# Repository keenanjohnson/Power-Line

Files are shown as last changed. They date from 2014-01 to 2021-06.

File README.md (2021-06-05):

###Current design###
4 "devices", communication is from top to bottom and vice versa:

* Arduino + Ethernet Shield -> (Ethernet cable) -> Router
* Router -> (Ethernet cable) -> PLN 1
* PLN 1 -> power line -> PLN 2
* PLN 2 -> (Ethernet cable) -> Arduino + Ethernet Sheild

####Information####
Ensure that the node devices all have different MAC addresses to get different IP addresses from the host router. The router should be set up to deliver a certain IP address to the MAC address of the base station. In our project's current state, it is meant to be delivered 192.168.2.50 but will setup its own IP address if that one is unobtainable. The nodes will just listen for the IP address so this is mainly important for access the website, which you will require you to know the IP address.

###Powerline###
Powerline

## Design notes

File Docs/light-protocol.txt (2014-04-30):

LIGHT PROTOCOL
DRAFT v2, 29 April 2014

The packets sent in the light protocol start with an identifier byte of 0x01, followed by protocol-specific information.

The protocol-specific information consists of a one-byte node identifier, a one-byte command, and a one-byte data field.

Nodes should only interpret a command whose node identifier byte matches their stored identifier. The implemented commands are as follows:

NODE_OFF = 0
Turn the light attached to a node off.

NODE_ON = 1
Turn the light attached to a node on.

NODE_SAVE_ID = 2
Set the stored identifier of a node to the data byte.

NODE_KEEP_ALIVE = 3
Ping message sent to ensure transport liveness.

NODE_STATUS = 4
Send the status of a node to the server in the data byte, using 0 for off and 1 for on.

In packets for which the command byte does not specify a command which uses the data byte, the value in the data byte is unspecified and should be ignored.

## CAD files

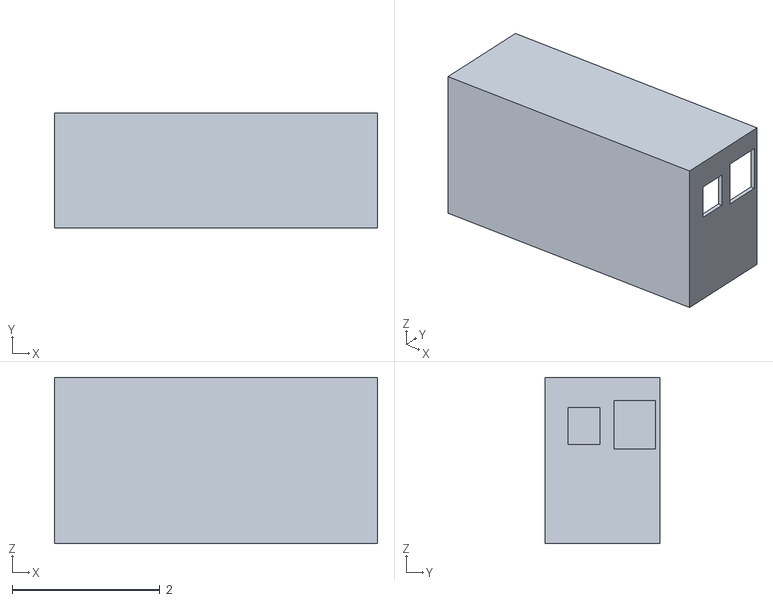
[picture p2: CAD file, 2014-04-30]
Hardware/PhysicalHousing/SD_BaseStation_Box.stl
4.37 x 1.56 x 2.25

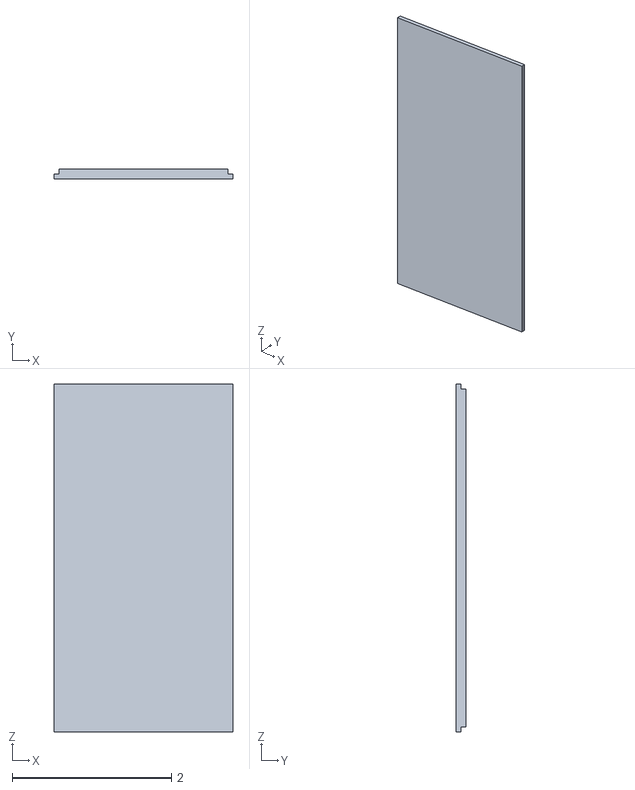
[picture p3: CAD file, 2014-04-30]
Hardware/PhysicalHousing/SD_BaseStation_Lid.stl
2.25 x 0.125 x 4.38

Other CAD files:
Hardware/PhysicalHousing/SD_BaseStation_Box.ipt
Hardware/PhysicalHousing/SD_BaseStation_Enclosure.iam
Hardware/PhysicalHousing/SD_BaseStation_Lid.ipt

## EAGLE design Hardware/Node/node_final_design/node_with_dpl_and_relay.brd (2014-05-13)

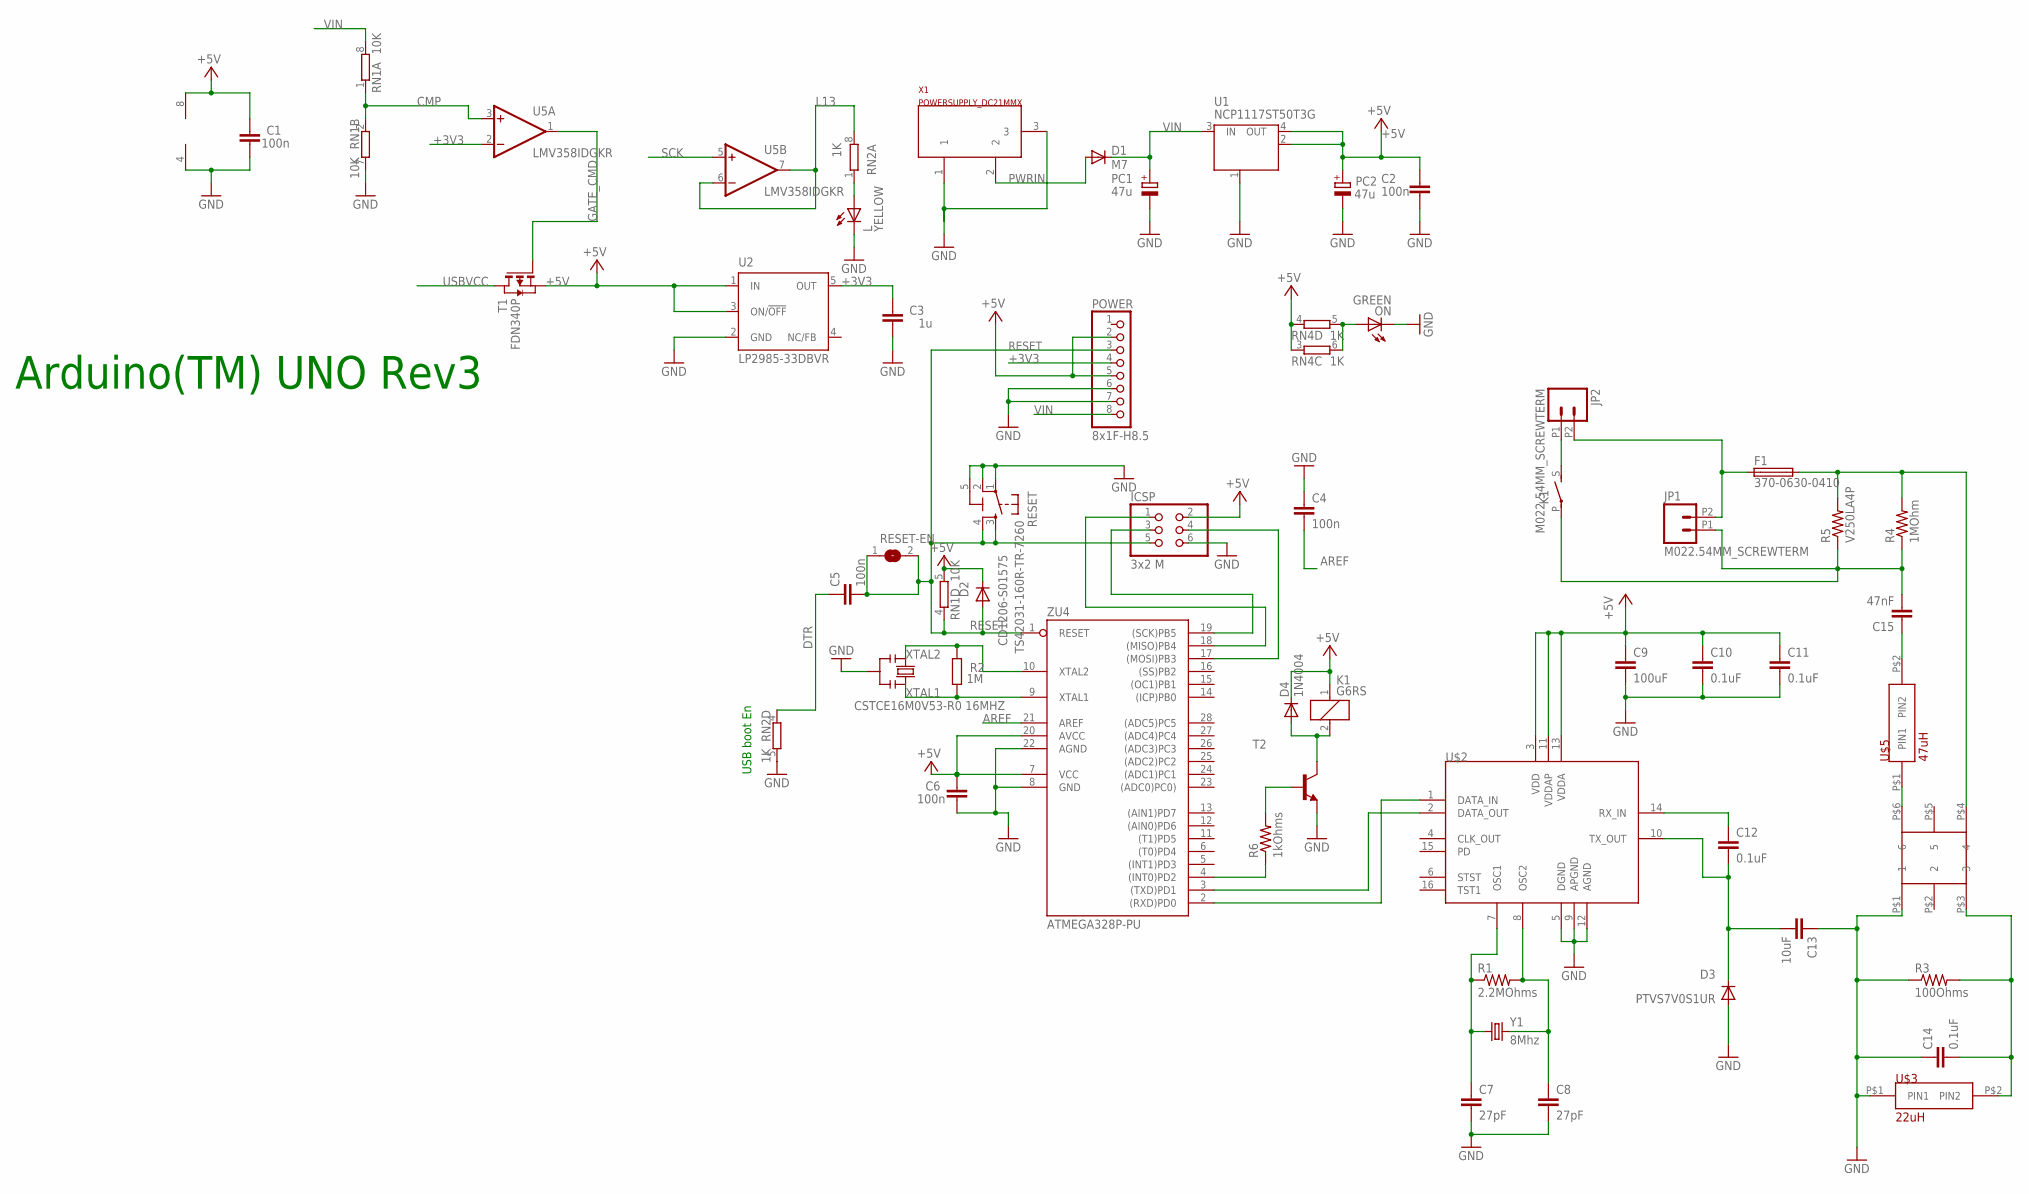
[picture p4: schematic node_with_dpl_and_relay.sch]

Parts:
C1, C2, C4, C5, C6: 100n; C0603-ROUND
C3: 1u; C0603-ROUND
C7, C8: 27pF; 1206
C9: 100uF; 1206
C10, C11, C14: 0.1uF; 1206
C12: 0.1uF; AXIAL-5MM
C13: 10uF; CAP-PTH-SMALL
C15: 47nF; C15B5
D1: M7; SMB
D2: CD1206-S01575; MINIMELF
D3: PTVS7V0S1UR; SOD-123_MINI-SMA
D4: 1N4004; DO41-10
F1: 370-0630-0410; TR5
ICSP: 3x2 M; 2X03
JP1, JP2: M022.54MM_SCREWTERM; 1X02_2.54_SCREWTERM
K1: G6RS
L: YELLOW; CHIP-LED0805
ON: GREEN; CHIP-LED0805
PC1, PC2: 47u; PANASONIC_D
POWER: 8x1F-H8.5; 1X08
R1: 2.2MOhms; 1206
R2: 1M; R0603-ROUND
R3: 100Ohms; AXIAL-0.5
R4: 1MOhm; AXIAL-0.3-KIT
R5: V250LA4P; AXIAL-0.4
R6: 1kOhms; 0204V
RESET: TS42031-160R-TR-7260; TS42
RESET-EN: SJ
RN1: 10K; CAY16
RN2, RN4: 1K; CAY16
T1: FDN340P; SOT-23
T2: 2N5401-NPN-TO92-CBE; TO92-CBE
U1: NCP1117ST50T3G; SOT223
U2: LP2985-33DBVR; SOT23-DBV
U5: LMV358IDGKR; MSOP08
U$2: TDA5052AT; SO16L
U$3: 22uH; RFB0807-220L
U$4: 78250MC
U$5: 47uH; RFB0807-220L
X1: POWERSUPPLY_DC21MMX; POWERSUPPLY_DC-21MM
Y1: 8Mhz; HC49US
Y2: CSTCE16M0V53-R0 16MHZ; RESONATOR
ZU4: ATMEGA328P-PU; DIL28-3

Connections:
+3V3: C3.2, POWER.4, U2.5 (OUT), U5.2 (-IN)
+5V: C1.2, C2.2, C6.2, C9.1, C10.1, C11.1, D2.C, D4.C, ICSP.2, K1.1, PC2.+, POWER.2, POWER.5, RN1.5 (2), RN4.3 (1), RN4.4 (1), T1.2 (S), U1.2 (OUT), U1.4 (OUT), U2.1 (IN), U2.3 (ON/!OFF), U5.8 (V+), U$2.3 (VDD), U$2.11 (VDDAP), U$2.13 (VDDA), ZU4.7 (VCC), ZU4.20 (AVCC)
AREF: C4.2, ZU4.21 (AREF)
CMP: RN1.1, RN1.2 (1), U5.3 (+IN)
DTR: C5.1, RN2.4 (1)
GATE_CMD: T1.3 (G), U5.1 (OUT)
GND: C1.1, C2.1, C3.1, C4.1, C6.1, C7.2, C8.2, C9.2, C10.2, C11.2, C13.1, C14.1, D3.A, ICSP.6, L.C, ON.C, PC1.-, PC2.-, POWER.6, POWER.7, R3.P$1 (1), RESET.1, RESET.2, RESET.5 (5-GND), RN1.7 (2), RN2.5 (2), T2.E, U1.1 (GND/ADJ), U2.2 (GND), U5.4 (V-), U$2.5 (DGND), U$2.9 (APGND), U$2.12 (AGND), U$3.P$1 (PIN1), U$4.P$1 (1), X1.1, X1.3, Y2.2, ZU4.8 (GND), ZU4.22 (AGND)
L13: RN2.8 (2), U5.6 (-IN), U5.7 (OUT)
MISO: ICSP.1, ZU4.18 ((MISO)PB4)
MOSI: ICSP.4, ZU4.17 ((MOSI)PB3)
unnamed: L.A, RN2.1
unnamed: C8.1, R1.2, U$2.8 (OSC2), Y1.2
unnamed: ON.A, RN4.5 (2), RN4.6 (2)
unnamed: C7.1, R1.1, U$2.7 (OSC1), Y1.1
unnamed: C12.P$1 (1), U$2.14 (RX_IN)
unnamed: C12.P$2 (2), C13.2, D3.C, U$2.10 (TX_OUT)
unnamed: C14.2, R3.P$2 (2), U$3.P$2 (PIN2), U$4.P$3 (3)
unnamed: U$4.P$6 (6), U$5.P$1 (PIN1)
unnamed: C15.1, U$5.P$2 (PIN2)
unnamed: F1.2, R4.P$2 (2), R5.P$2 (2), U$4.P$4 (4)
unnamed: JP2.P1 (1), K1.S
unnamed: F1.1, JP1.P2 (2), JP2.P2 (2)
unnamed: U$2.2 (DATA_OUT), ZU4.3 ((TXD)PD1)
unnamed: U$2.1 (DATA_IN), ZU4.2 ((RXD)PD0)
unnamed: R6.1, ZU4.4 ((INT0)PD2)
unnamed: R6.2, T2.B
unnamed: D4.A, K1.2, T2.C
unnamed: C15.2, JP1.P1 (1), K1.P, R4.P$1 (1), R5.P$1 (1)
PWRIN: D1.A, X1.2
RESET: C5.2, D2.A, ICSP.5, POWER.3, RESET.3, RESET.4, RESET-EN.1, RESET-EN.2, RN1.4 (1), ZU4.1 (RESET)
SCK: ICSP.3, U5.5 (+IN), ZU4.19 ((SCK)PB5)
USBVCC: T1.1 (D)
VIN: D1.C, PC1.+, POWER.8, RN1.8 (2), U1.3 (IN)
XTAL1: R2.1, Y2.3, ZU4.9 (XTAL1)
XTAL2: R2.2, Y2.1, ZU4.10 (XTAL2)

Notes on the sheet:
Arduino(TM) UNO Rev3
USB boot En

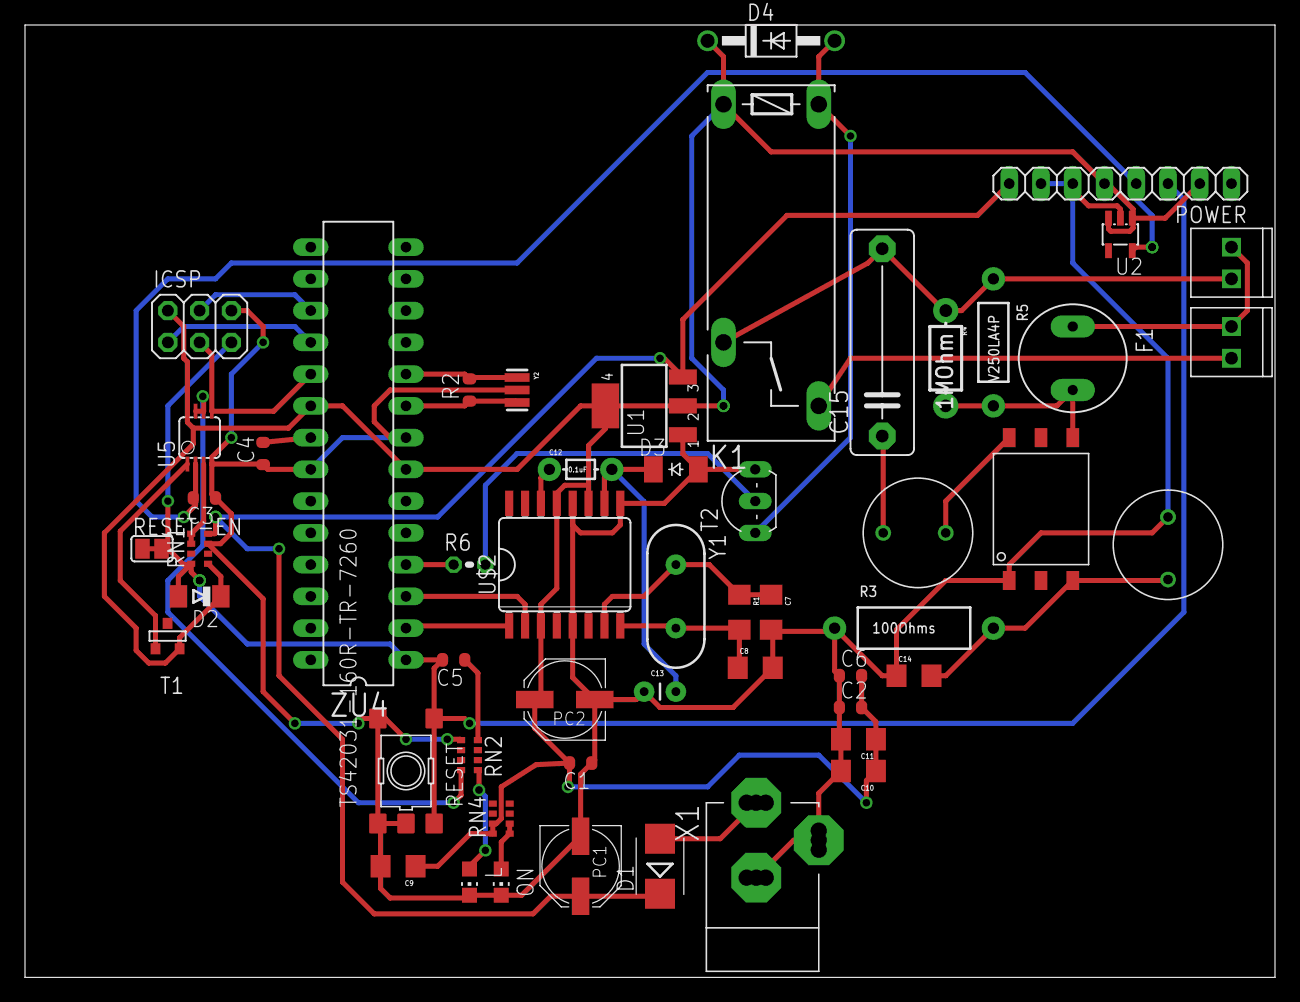
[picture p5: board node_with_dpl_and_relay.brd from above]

Board: 2 copper layers, 100.0 x 76.2 mm, 53 parts (0 on the bottom side), 34 nets.

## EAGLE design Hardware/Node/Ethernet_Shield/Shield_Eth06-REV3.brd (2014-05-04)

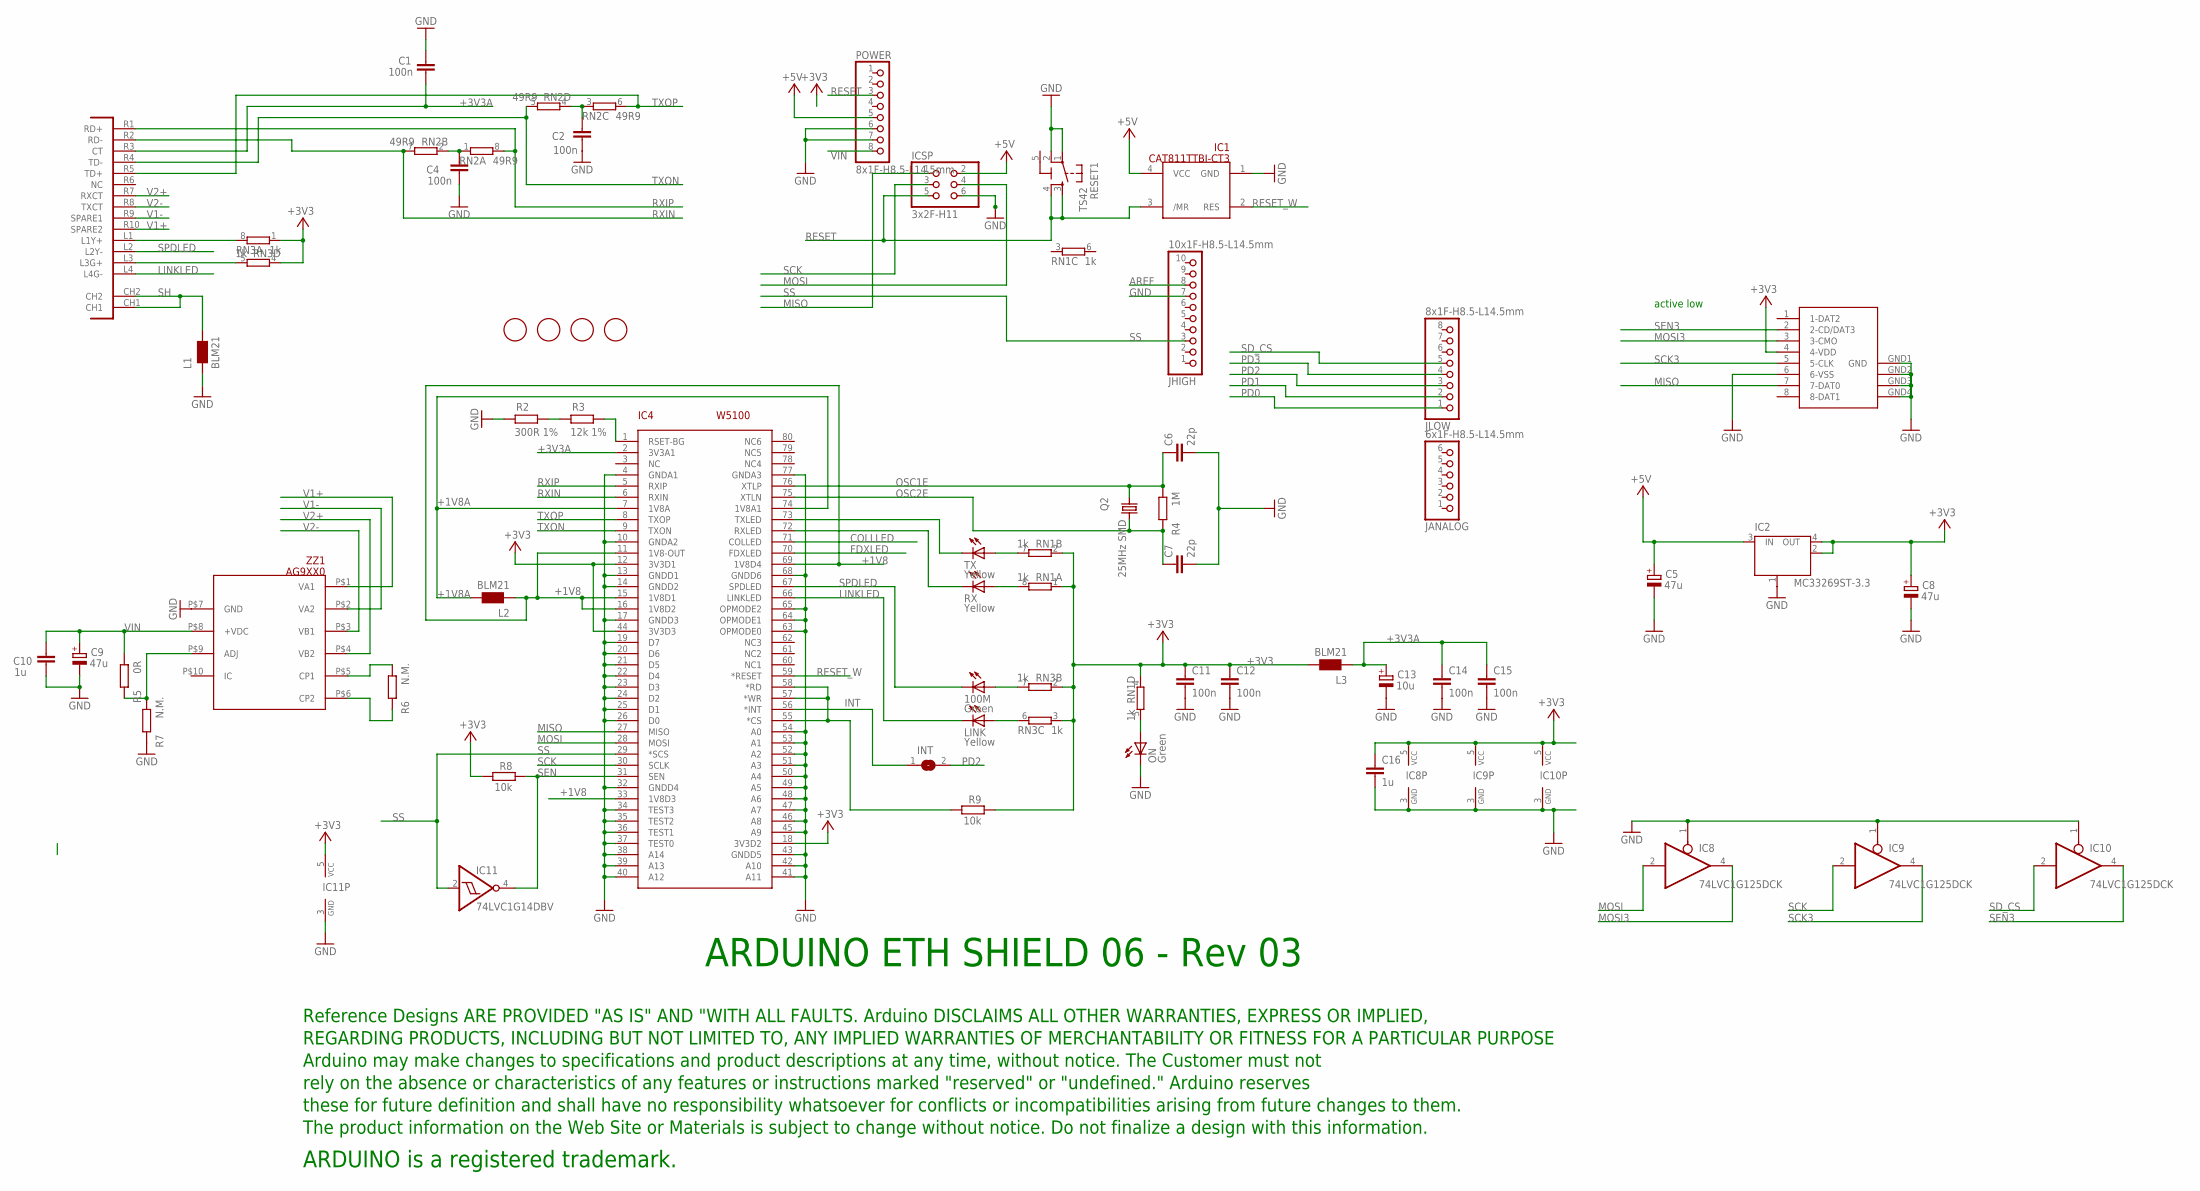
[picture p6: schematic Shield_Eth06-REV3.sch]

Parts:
100M: Green; CHIPLED_0805
C1, C2, C4, C11, C12, C14, C15: 100n; C0603-ROUND
C5, C8, C9: 47u; PANASONIC_D
C6, C7: 22p; C0603-ROUND
C10, C16: 1u; C0603-ROUND
C13: 10u; SMC_B
FID1, FID2, FID3, FID4: FIDUCIALMOUNT; FIDUCIA-MOUNT
IC1: CAT811TTBI-CT3; SOT143
IC2: MC33269ST-3.3; SOT223
IC4: W5100; SQFP-S-10X10-80
IC8, IC9, IC10: 74LVC1G125DCK; SC70-5
IC11: 74LVC1G14DBV; SOT23-5
ICSP: 3x2F-H11; 2X03
INT: SJ
JANALOG: 6x1F-H8.5-L14.5mm; 1X06
JHIGH: 10x1F-H8.5-L14.5mm; 1X10
JLOW: 8x1F-H8.5-L14.5mm; 1X08
L1, L2, L3: BLM21; 0805
LINK: Yellow; CHIPLED_0805
ON: Green; CHIPLED_0805
POWER: 8x1F-H8.5-L14.5mm; 1X08
Q2: 25MHz SMD; HC49UP
R2: 300R 1%; R0603-ROUND
R3: 12k 1%; R0603-ROUND
R4: 1M; R0603-ROUND
R5: 0R; R0603-ROUND
R6, R7: N.M.; R0603-ROUND
R8, R9: 10k; R0603-ROUND
RESET1: TS42
RN1, RN3: 1k; CAY16
RN2: 49R9; CAY16
RX: Yellow; CHIPLED_0805
TX: Yellow; CHIPLED_0805
U$1: POE-RJ45
U$2: DISCLAIMER
X1: SDCARD-15TW-8821
ZZ1: AG9XX0; AG9000

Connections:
5-GND: RESET1.5 (5-GND)
+1V8: IC4.11 (1V8-OUT), IC4.15 (1V8D1), IC4.16 (1V8D2), IC4.33 (1V8D3), IC4.69 (1V8D4), L2.1
+1V8A: IC4.7 (1V8A), IC4.74 (1V8A1), L2.2
+3V3: C8.+, C11.1, C12.1, C16.1, IC2.2 (OUT), IC2.4 (OUT), IC4.12 (3V3D1), IC4.18 (3V3D2), IC4.44 (3V3D3), IC8.5 (VCC), IC9.5 (VCC), IC10.5 (VCC), IC11.5 (VCC), L3.2, R8.1, R9.2, RN1.1, RN1.2 (1), RN1.4 (1), RN3.1, RN3.2 (1), RN3.3 (1), RN3.4 (1), X1.4 (4-VDD)
+3V3A: C1.1, C13.+, C14.1, C15.1, IC4.2 (3V3A1), L3.1, U$1.R3 (CT)
+5V: C5.+, IC1.4 (VCC), IC2.3 (IN), ICSP.2, POWER.5
AREF: JHIGH.8
COLLLED: IC4.71 (COLLED)
FDXLED: IC4.70 (FDXLED)
GND: C1.2, C2.1, C4.1, C5.-, C6.2, C7.2, C8.-, C9.-, C10.1, C11.2, C12.2, C13.-, C14.2, C15.2, C16.2, IC1.1 (GND), IC2.1 (GND/ADJ), IC4.4 (GNDA1), IC4.10 (GNDA2), IC4.13 (GNDD1), IC4.14 (GNDD2), IC4.17 (GNDD3), IC4.19 (D7), IC4.20 (D6), IC4.21 (D5), IC4.22 (D4), IC4.23 (D3), IC4.24 (D2), IC4.25 (D1), IC4.26 (D0), IC4.32 (GNDD4), IC4.34 (TEST3), IC4.35 (TEST2), IC4.36 (TEST1), IC4.37 (TEST0), IC4.38 (A14), IC4.39 (A13), IC4.40 (A12), IC4.41 (A11), IC4.42 (A10), IC4.43 (GNDD5), IC4.45 (A9), IC4.46 (A8), IC4.47 (A7), IC4.48 (A6), IC4.49 (A5), IC4.50 (A4), IC4.51 (A3), IC4.52 (A2), IC4.53 (A1), IC4.54 (A0), IC4.63 (OPMODE0), IC4.64 (OPMODE1), IC4.65 (OPMODE2), IC4.68 (GNDD6), IC4.77 (GNDA3), IC8.1 (OE), IC8.3 (GND), IC9.1 (OE), IC9.3 (GND), IC10.1 (OE), IC10.3 (GND), IC11.3 (GND), ICSP.6, JHIGH.7, L1.1, ON.C, POWER.6, POWER.7, R2.2, R7.2, RESET1.1, RESET1.2, X1.6 (6-VSS), X1.GND1 (GND), X1.GND2 (GND1), X1.GND3 (GND2), X1.GND4 (GND3), ZZ1.P$7 (GND)
INT: IC4.56 (*INT), INT.1
LINKLED: IC4.66 (LINKLED), LINK.C, U$1.L4 (L4G-)
MISO: IC4.27 (MISO), ICSP.1, X1.7 (7-DAT0)
MOSI: IC4.28 (MOSI), IC8.2 (I), ICSP.4
MOSI3: IC8.4 (O), X1.3 (3-CMO)
unnamed: RN3.5 (2), U$1.L3 (L3G+)
unnamed: RN3.8 (2), U$1.L1 (L1Y+)
unnamed: IC4.73 (TXLED), TX.C
unnamed: IC4.72 (RXLED), RX.C
unnamed: ON.A, RN1.5 (2)
unnamed: RN1.7 (2), TX.A
unnamed: C2.2, RN2.3 (1), RN2.4 (1)
unnamed: RN1.8 (2), RX.A
unnamed: 100M.A, RN3.7 (2)
unnamed: LINK.A, RN3.6 (2)
unnamed: C4.2, RN2.1, RN2.2 (1)
unnamed: R2.1, R3.2
unnamed: IC4.1 (RSET-BG), R3.1
unnamed: R6.1, ZZ1.P$5 (CP1)
unnamed: R6.2, ZZ1.P$6 (CP2)
unnamed: R5.2, R7.1, ZZ1.P$9 (ADJ)
unnamed: IC4.55 (*CS), IC4.57 (*WR), IC4.58 (*RD), R9.1
OSC1E: C6.1, IC4.76 (XTLP), Q2.1, R4.1
OSC2E: C7.1, IC4.75 (XTLN), Q2.2, R4.2
PD0: JLOW.1
PD1: JLOW.2
PD2: INT.2, JLOW.3
PD3: JLOW.4
RESET: IC1.3 (/MR), ICSP.5, POWER.3, RESET1.3, RESET1.4
RESET_W: IC1.2 (RES), IC4.59 (*RESET)
RXIN: IC4.6 (RXIN), RN2.7 (2), U$1.R2 (RD-)
RXIP: IC4.5 (RXIP), RN2.8 (2), U$1.R1 (RD+)
SCK: IC4.30 (SCLK), IC9.2 (I), ICSP.3
SCK3: IC9.4 (O), X1.5 (5-CLK)
SD_CS: IC10.2 (I), JLOW.5
SEN: IC4.31 (SEN), IC11.4 (O), R8.2
SEN3: IC10.4 (O), X1.2 (2-CD/DAT3)
SH: L1.2, U$1.CH1, U$1.CH2
SPDLED: 100M.C, IC4.67 (SPDLED), U$1.L2 (L2Y-)
SS: IC4.29 (*SCS), IC11.2 (I), JHIGH.3
TXON: IC4.9 (TXON), RN2.5 (2), U$1.R4 (TD-)
TXOP: IC4.8 (TXOP), RN2.6 (2), U$1.R5 (TD+)
V1+: U$1.R10 (SPARE2), ZZ1.P$1 (VA1)
V1-: U$1.R9 (SPARE1), ZZ1.P$2 (VA2)
V2+: U$1.R7 (RXCT), ZZ1.P$4 (VB2)
V2-: U$1.R8 (TXCT), ZZ1.P$3 (VB1)
VIN: C9.+, C10.2, POWER.8, R5.1, ZZ1.P$8 (+VDC)

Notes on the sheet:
ARDUINO ETH SHIELD 06 - Rev 03
active low

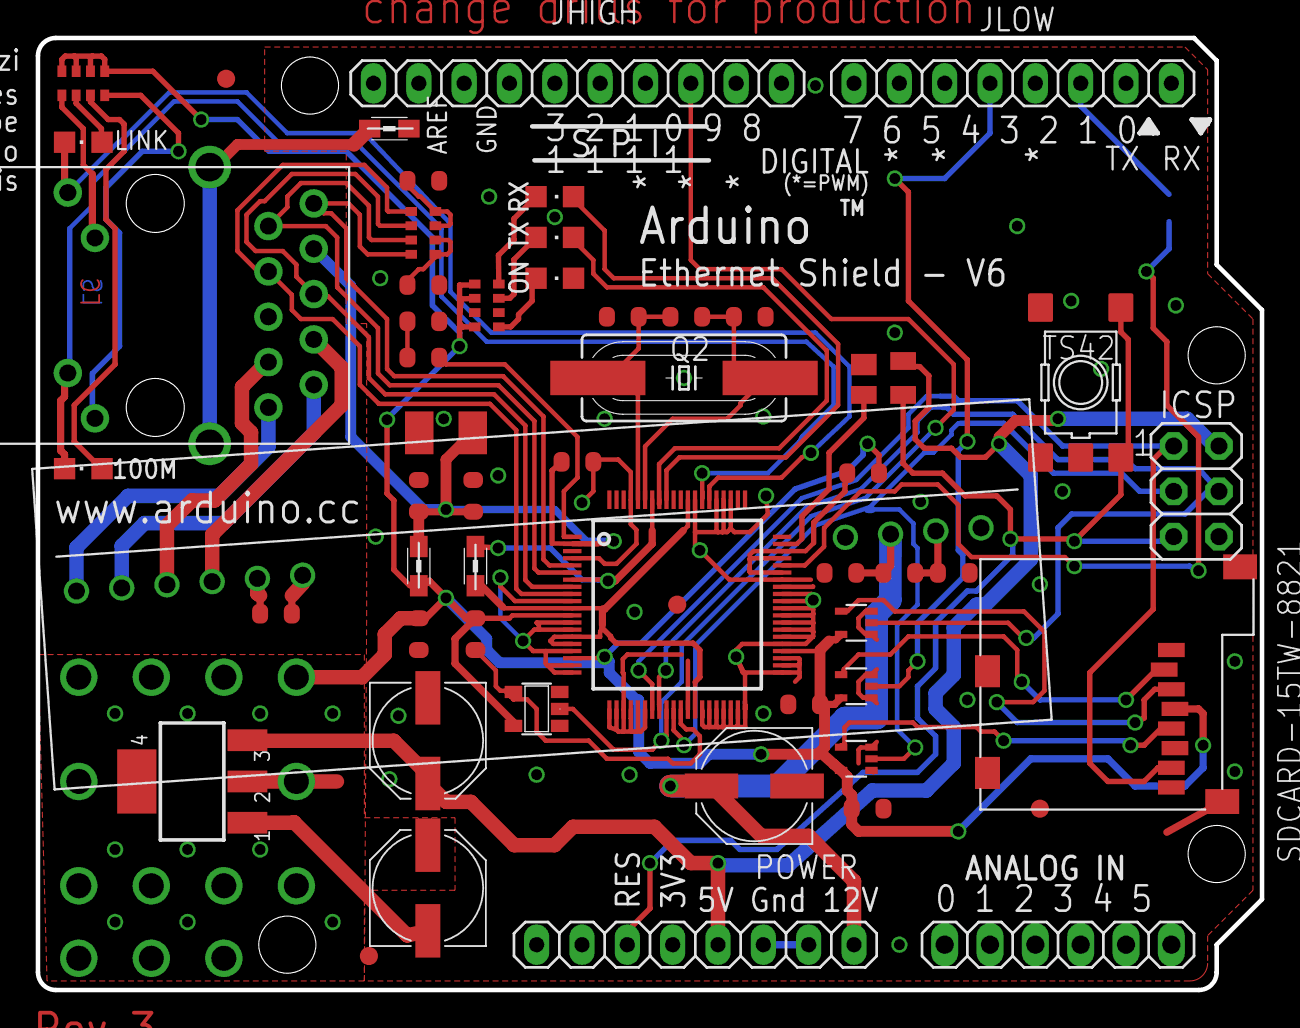
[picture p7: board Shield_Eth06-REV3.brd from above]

Board: 2 copper layers, 68.6 x 53.3 mm, 57 parts (1 on the bottom side), 50 nets.

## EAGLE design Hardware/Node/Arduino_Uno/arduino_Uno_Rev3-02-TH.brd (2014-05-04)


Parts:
AD: 6x1F-H8.5; 1X06
C1, C2, C4, C5, C6, C7: 100n; C0603-ROUND
C3, C8: 1u; C0603-ROUND
C9, C11: 22p; C0603-ROUND
D1: M7; SMB
D2, D3: CD1206-S01575; MINIMELF
F1: MF-MSMF050-2 500mA; L1812
FD1, FD2, FD3: FIDUCIALMOUNT; FIDUCIA-MOUNT
GROUND: SJ
ICSP, ICSP1: 3x2 M; 2X03
IOH: 10x1F-H8.5; 1X10
IOL: 8x1F-H8.5; 1X08
JP2: 2x2 M - NM; 2X02
L: YELLOW; CHIP-LED0805
L1: BLM21; 0805
ON: GREEN; CHIP-LED0805
PC1, PC2: 47u; PANASONIC_D
POWER: 8x1F-H8.5; 1X08
R1, R2: 1M; R0603-ROUND
RESET: TS42031-160R-TR-7260; TS42
RESET-EN: SJ
RN1: 10K; CAY16
RN2, RN4: 1K; CAY16
RN3: 22R; CAY16
RX: YELLOW; CHIP-LED0805
T1: FDN340P; SOT-23
TX: YELLOW; CHIP-LED0805
U1: NCP1117ST50T3G; SOT223
U2: LP2985-33DBVR; SOT23-DBV
U3: ATMEGA16U2-MU(R); MLF32
U5: LMV358IDGKR; MSOP08
U$1: DISCLAIMER
X1: POWERSUPPLY_DC21MMX; POWERSUPPLY_DC-21MM
X2: USB-B_TH; PN61729
Y1: 16MHz; QS
Y2: CSTCE16M0V53-R0 16MHZ; RESONATOR
Z1, Z2: CG0603MLC-05E; CT/CN0603
ZU4: ATMEGA328P-PU; DIL28-3

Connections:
5-GND: RESET.5 (5-GND)
+3V3: C3.2, POWER.4, U2.5 (OUT), U5.2 (-IN)
+5V: C1.2, C2.2, C6.2, C7.1, D2.C, D3.C, ICSP.2, ICSP1.2, PC2.+, POWER.2, POWER.5, RN1.3 (1), RN1.5 (2), RN2.2 (1), RN2.3 (1), RN4.3 (1), RN4.4 (1), T1.2 (S), U1.2 (OUT), U1.4 (OUT), U2.1 (IN), U2.3 (ON/!OFF), U3.4 (VCC), U3.32 (AVCC), U5.8 (V+), ZU4.7 (VCC), ZU4.20 (AVCC)
AD0: AD.1, ZU4.23 ((ADC0)PC0))
AD1: AD.2, ZU4.24 ((ADC1)PC1)
AD2: AD.3, ZU4.25 ((ADC2)PC2)
AD3: AD.4, ZU4.26 ((ADC3)PC3)
AD4/SDA: AD.5, IOH.9, ZU4.27 ((ADC4)PC4)
AD5/SCL: AD.6, IOH.10, ZU4.28 ((ADC5)PC5)
AREF: C4.2, IOH.8, ZU4.21 (AREF)
CMP: RN1.1, RN1.2 (1), U5.3 (+IN)
D+: RN3.5 (2), X2.3, Z1.1
D-: RN3.8 (2), X2.2, Z2.1
DTR: C5.1, RN2.4 (1), U3.13 ((CTS/HWB/AIN6/TO/INT7)PD7)
GATE_CMD: T1.3 (G), U5.1 (OUT)
GND: C1.1, C2.1, C3.1, C4.1, C6.1, C7.2, C9.2, C11.2, GROUND.1, ICSP.6, ICSP1.6, IOH.7, L.C, ON.C, PC1.-, PC2.-, POWER.6, POWER.7, RESET.1, RESET.2, RN1.7 (2), RN2.5 (2), U1.1 (GND/ADJ), U2.2 (GND), U3.3 (GND), U3.33 (PAD), U5.4 (V-), X1.1, X1.3, Y2.2, ZU4.8 (GND), ZU4.22 (AGND)
IO0: IOL.1, RN4.2 (1), ZU4.2 ((RXD)PD0)
IO1: IOL.2, RN4.1, ZU4.3 ((TXD)PD1)
IO2: IOL.3, ZU4.4 ((INT0)PD2)
IO3: IOL.4, ZU4.5 ((INT1)PD3)
IO4: IOL.5, ZU4.6 ((T0)PD4)
IO5: IOL.6, ZU4.11 ((T1)PD5)
IO6: IOL.7, ZU4.12 ((AIN0)PD6)
IO7: IOL.8, ZU4.13 ((AIN1)PD7)
IO8: IOH.1, ZU4.14 ((ICP)PB0)
IO9: IOH.2, ZU4.15 ((OC1)PB1)
L13: RN2.8 (2), U5.6 (-IN), U5.7 (OUT)
M8RXD: RN4.7 (2), U3.9 ((TXD1/INT3)PD3)
M8TXD: RN4.8 (2), U3.8 ((RXD1/AIN1/INT2)PD2)
MISO: ICSP.1, IOH.5, ZU4.18 ((MISO)PB4)
MISO2: ICSP1.1, U3.17 ((PD0/MISO/PCINT3)PB3)
MOSI: ICSP.4, IOH.4, ZU4.17 ((MOSI)PB3)
MOSI2: ICSP1.4, U3.16 ((PDI/MOSI/PCINT2)PB2)
unnamed: L.A, RN2.1
unnamed: ON.A, RN4.5 (2), RN4.6 (2)
unnamed: RN2.7 (2), RX.A
unnamed: RN2.6 (2), TX.A
PB4: JP2.1, U3.18 ((T1/PCINT4)PB4)
PB5: JP2.3, U3.19 ((PCINT5)PB5)
PB6: JP2.2, U3.20 ((PCINT6)PB6)
PB7: JP2.4, U3.21 ((PCINT7/OC0A/OC1C)PB7)
PWRIN: D1.A, X1.2
RD+: RN3.4 (1), U3.29 (D+)
RD-: RN3.1, U3.30 (D-)
RESET: C5.2, D2.A, ICSP.5, POWER.3, RESET.3, RESET.4, RESET-EN.1, RESET-EN.2, RN1.4 (1), ZU4.1 (RESET)
RESET2: D3.A, ICSP1.5, RN1.6 (2), U3.24 (RESET(PC1/DW))
RXLED: RX.C, U3.10 ((INT5/AIN3)PD4)
SCK: ICSP.3, IOH.6, U5.5 (+IN), ZU4.19 ((SCK)PB5)
SCK2: ICSP1.3, U3.15 ((SCLK/PCINT1)PB1)
SS: IOH.3, ZU4.16 ((SS)PB2)
TP_VUCAP: C8.1, U3.27 (UCAP)
TXLED: TX.C, U3.11 ((XCK/AIN4/PCINT12)PD5)
UGND: C8.2, GROUND.2, L1.1, U3.28 (UGND), X2.4
USBVCC: F1.1, T1.1 (D), U3.31 (UVCC)
USHIELD: L1.2, X2.P$1, X2.P$2, Z1.2, Z2.2
VIN: D1.C, PC1.+, POWER.8, RN1.8 (2), U1.3 (IN)
XT1: C9.1, R1.1, U3.1 (XTAL1), Y1.2
XT2: C11.1, R1.2, U3.2 (XTAL2(PC0)), Y1.1
XTAL1: R2.1, Y2.3, ZU4.9 (XTAL1)
XTAL2: R2.2, Y2.1, ZU4.10 (XTAL2)
XUSB: F1.2, X2.1

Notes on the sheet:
Arduino(TM) UNO Rev3
USB boot En
SDA
SCL
Use of the ARDUINO name must be compliant with http://www.arduino.cc/en/Main/Policy


Board: 2 copper layers, 68.6 x 53.3 mm, 53 parts (1 on the bottom side), 60 nets.

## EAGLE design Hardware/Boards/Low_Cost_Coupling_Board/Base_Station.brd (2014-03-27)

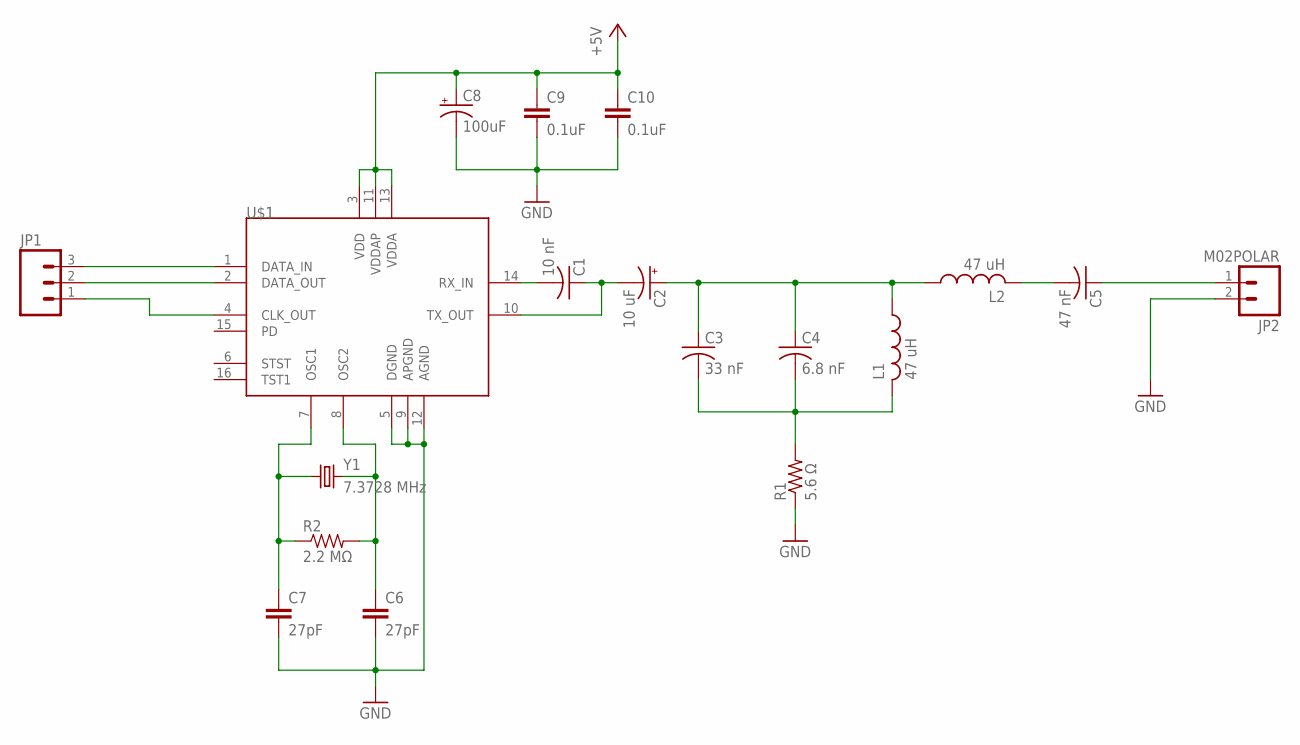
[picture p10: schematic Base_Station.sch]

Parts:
C1: 10 nF; C025-030X050
C2: 10 uF; E2-5
C3: 33 nF; C050-050X075
C4: 6.8 nF; C102-043X133
C5: 47 nF; C075-063X106
C6, C7: 27pF; CAP-PTH-5MM
C8: 100uF; CPOL-RADIAL-100UF-25V
C9, C10: 0.1uF; CAP-PTH-5MM
JP1: M03POLAR; MOLEX-1X3
JP2: M02POLAR; MOLEX-1X2
L1: 47 uH; 0204/7
L2: 47 uH; 0207/10
R1: 5.6 Ω; 0207/7
R2: 2.2 MΩ; AXIAL-0.4
U$1: TDA5052AT; SO16L
Y1: 7.3728 MHz; HC49US

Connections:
+5V: C8.1 (+), C9.1, C10.1, U$1.3 (VDD), U$1.11 (VDDAP), U$1.13 (VDDA)
GND: C6.2, C7.2, C8.2 (-), C9.2, C10.2, JP2.2, R1.1, U$1.5 (DGND), U$1.9 (APGND), U$1.12 (AGND)
unnamed: C1.2, U$1.14 (RX_IN)
unnamed: C5.2, L2.2
unnamed: C1.1, C2.-, U$1.10 (TX_OUT)
unnamed: C2.+, C3.1, C4.1, L1.1, L2.1
unnamed: C3.2, C4.2, L1.2, R1.2
unnamed: C5.1, JP2.1
unnamed: C7.1, R2.P$1 (1), U$1.7 (OSC1), Y1.1
unnamed: C6.1, R2.P$2 (2), U$1.8 (OSC2), Y1.2
unnamed: JP1.3, U$1.1 (DATA_IN)
unnamed: JP1.2, U$1.2 (DATA_OUT)
unnamed: JP1.1, U$1.4 (CLK_OUT)

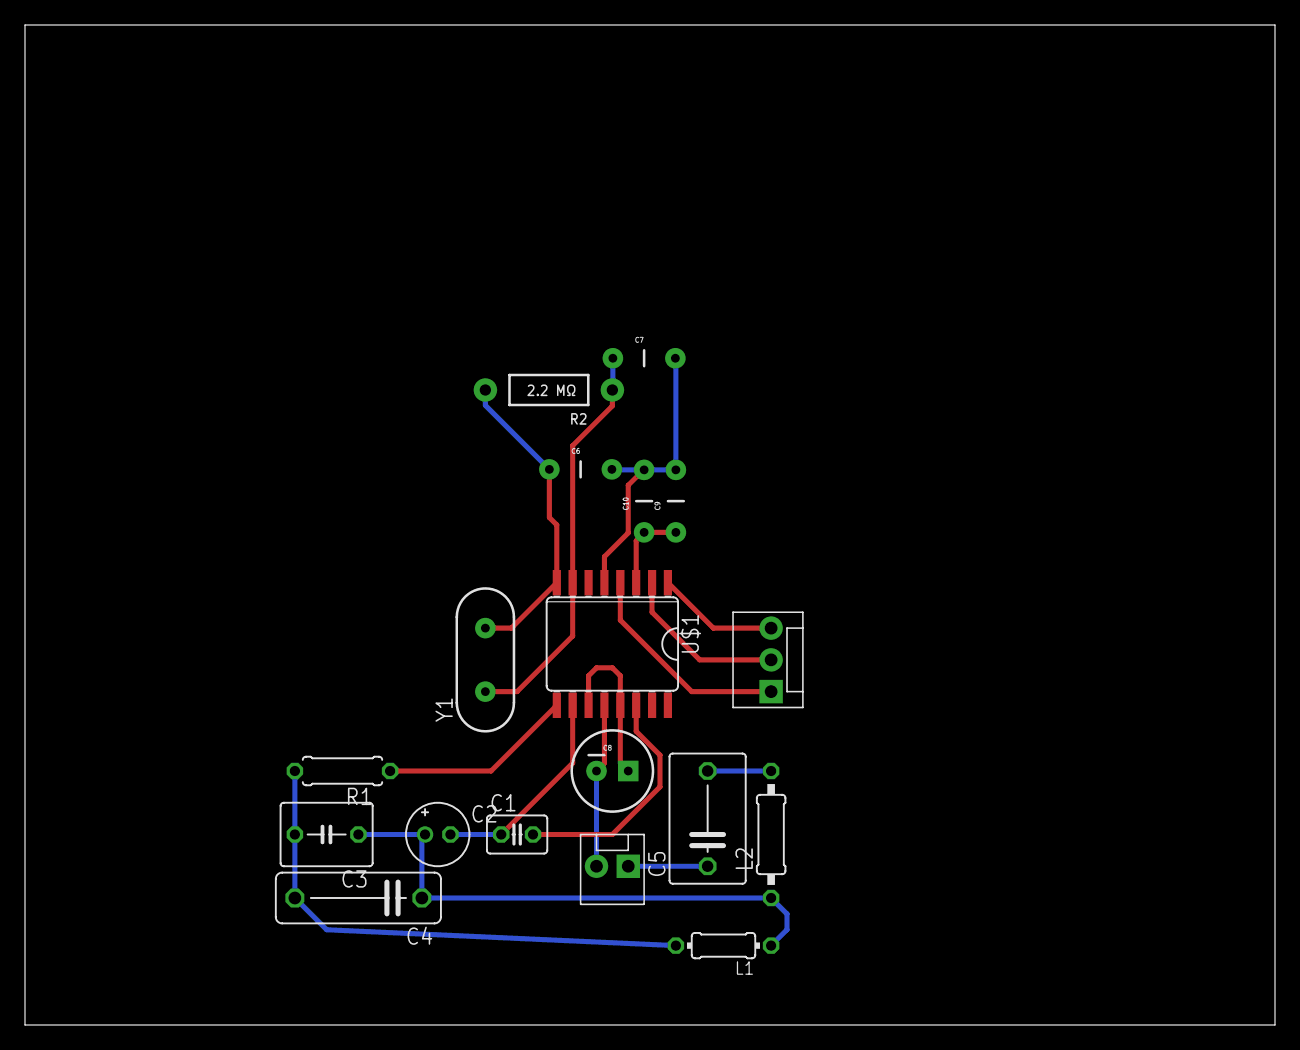
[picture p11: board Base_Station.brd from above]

Board: 2 copper layers, 100.0 x 80.0 mm, 18 parts (0 on the bottom side), 13 nets.

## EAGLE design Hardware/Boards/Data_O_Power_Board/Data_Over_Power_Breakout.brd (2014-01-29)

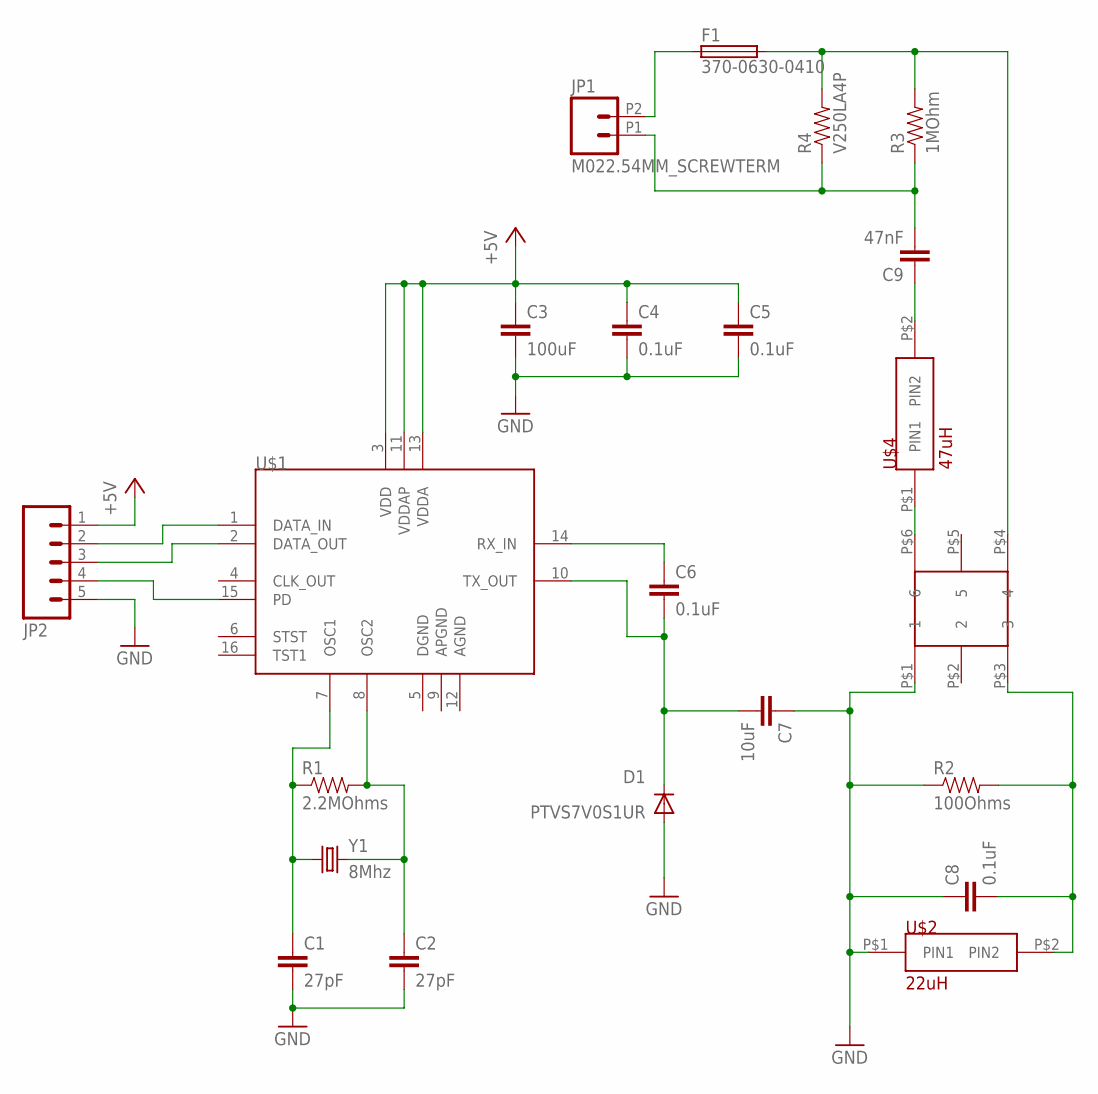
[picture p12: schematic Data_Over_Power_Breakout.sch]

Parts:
C1, C2: 27pF; 1206
C3: 100uF; 1206
C4, C5, C8: 0.1uF; 1206
C6: 0.1uF; AXIAL-5MM
C7: 10uF; CAP-PTH-SMALL
C9: 47nF; C15B5
D1: PTVS7V0S1UR; SOD-123_MINI-SMA
F1: 370-0630-0410; TR5
JP1: M022.54MM_SCREWTERM; 1X02_2.54_SCREWTERM
JP2: M05PTH_LONGPADS; 1X05_LONGPADS
R1: 2.2MOhms; 1206
R2: 100Ohms; AXIAL-0.5
R3: 1MOhm; AXIAL-0.3-KIT
R4: V250LA4P; AXIAL-0.4
U$1: TDA5052AT; SO16L
U$2: 22uH; RFB0807-220L
U$3: 78250MC
U$4: 47uH; RFB0807-220L
Y1: 8Mhz; HC49US

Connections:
+5V: C3.1, C4.1, C5.1, JP2.1, U$1.3 (VDD), U$1.11 (VDDAP), U$1.13 (VDDA)
GND: C1.2, C2.2, C3.2, C4.2, C5.2, C7.1, C8.1, D1.A, JP2.5, R2.P$1 (1), U$2.P$1 (PIN1), U$3.P$1 (1)
unnamed: C2.1, R1.2, U$1.8 (OSC2), Y1.2
unnamed: C1.1, R1.1, U$1.7 (OSC1), Y1.1
unnamed: U$3.P$6 (6), U$4.P$1 (PIN1)
unnamed: C8.2, R2.P$2 (2), U$2.P$2 (PIN2), U$3.P$3 (3)
unnamed: C6.P$1 (1), U$1.14 (RX_IN)
unnamed: C6.P$2 (2), C7.2, D1.C, U$1.10 (TX_OUT)
unnamed: C9.1, U$4.P$2 (PIN2)
unnamed: C9.2, JP1.P1 (1), R3.P$1 (1), R4.P$1 (1)
unnamed: F1.2, R3.P$2 (2), R4.P$2 (2), U$3.P$4 (4)
unnamed: F1.1, JP1.P2 (2)
unnamed: JP2.2, U$1.1 (DATA_IN)
unnamed: JP2.3, U$1.2 (DATA_OUT)
unnamed: JP2.4, U$1.15 (PD)

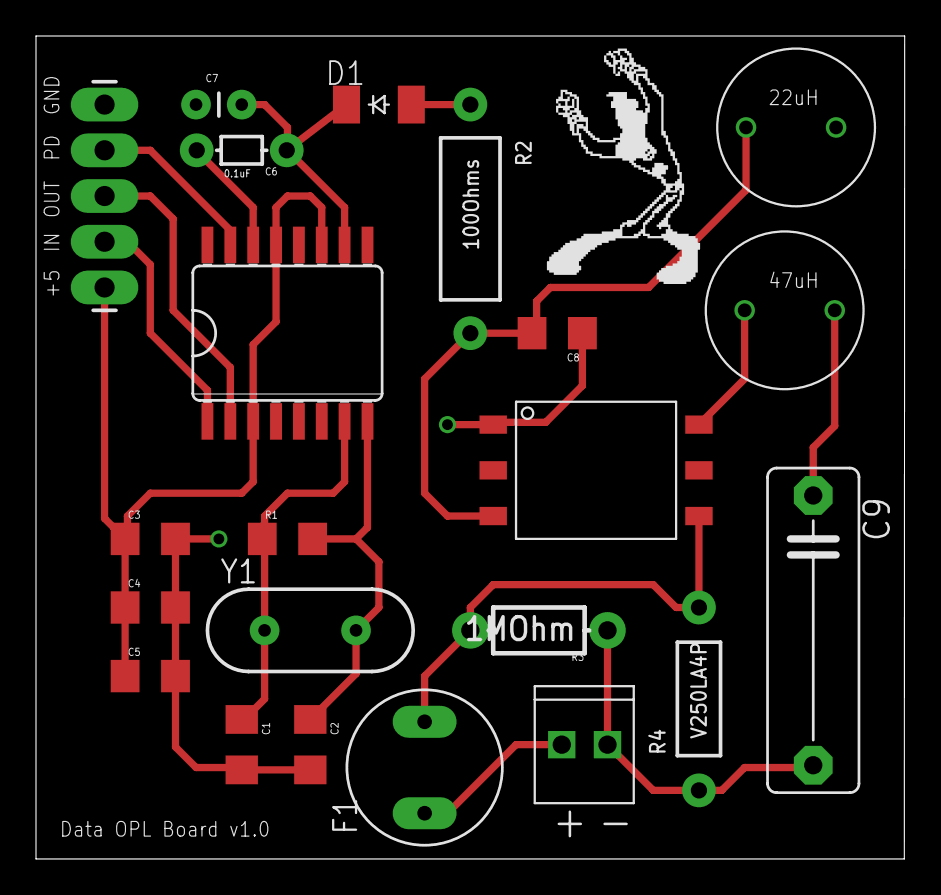
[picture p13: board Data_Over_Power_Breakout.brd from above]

Board: 2 copper layers, 48.3 x 45.7 mm, 22 parts (0 on the bottom side), 15 nets.

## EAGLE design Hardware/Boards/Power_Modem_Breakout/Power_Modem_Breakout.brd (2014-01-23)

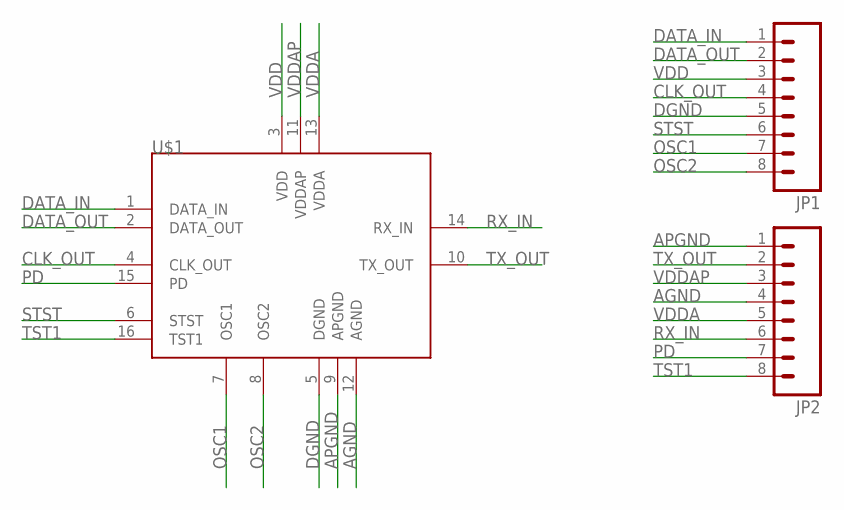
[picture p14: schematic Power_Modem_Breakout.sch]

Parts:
JP1, JP2: M08LONGPADS; 1X08_LONGPADS
U$1: TDA5052AT; SO16L

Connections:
AGND: JP2.4, U$1.12 (AGND)
APGND: JP2.1, U$1.9 (APGND)
CLK_OUT: JP1.4, U$1.4 (CLK_OUT)
DATA_IN: JP1.1, U$1.1 (DATA_IN)
DATA_OUT: JP1.2, U$1.2 (DATA_OUT)
DGND: JP1.5, U$1.5 (DGND)
OSC1: JP1.7, U$1.7 (OSC1)
OSC2: JP1.8, U$1.8 (OSC2)
PD: JP2.7, U$1.15 (PD)
RX_IN: JP2.6, U$1.14 (RX_IN)
STST: JP1.6, U$1.6 (STST)
TST1: JP2.8, U$1.16 (TST1)
TX_OUT: JP2.2, U$1.10 (TX_OUT)
VDD: JP1.3, U$1.3 (VDD)
VDDA: JP2.5, U$1.13 (VDDA)
VDDAP: JP2.3, U$1.11 (VDDAP)

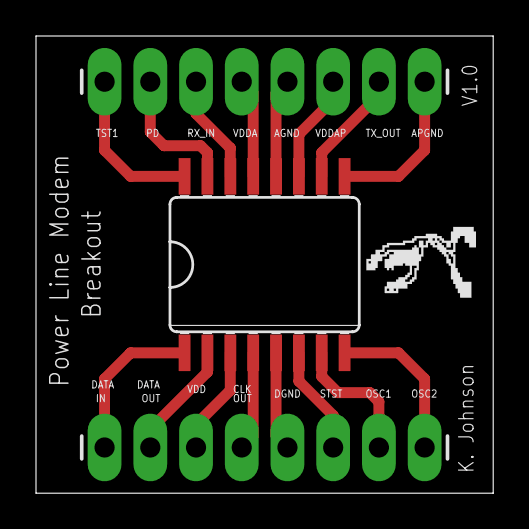
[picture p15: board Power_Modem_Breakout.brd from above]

Board: 2 copper layers, 25.4 x 25.4 mm, 3 parts (0 on the bottom side), 16 nets.

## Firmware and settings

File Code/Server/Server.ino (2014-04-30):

/*
  Arduino Server Basestation
 
 Server program to run Arduino + Ethernet shield plugged into router via
 Ethernet cable communicating to a PLN device also connected to the router
 via an Ethernet cable.
 
 Circuit:
 * Ethernet shield attached to pins 10, 11, 12, 13
 
 */

#include <SPI.h>
#include <Ethernet.h>
#include <SD.h>
#include <time.h>

#include "WebServer.h"

/*------------------------------------------------------------------------
CONSTANTS/TYPES
------------------------------------------------------------------------*/
//////////////////////////////////////////////////////////////////////////
// KEEP TWO SKETCHES IN SYNC BECAUSE ARDUINO'S IDE IS DUMB ///////////////
//////////////////////////////////////////////////////////////////////////
#define STATIC_ASSERT(COND,MSG) typedef char static_assertion_##MSG[(COND)?1:-1]

#define PACKET_WAIT_TIMEOUT 1000

typedef byte node_cmds; enum {
  NODE_OFF = 0,
  NODE_ON,
  NODE_SAVE_ID,
  NODE_KEEP_ALIVE,
  NODE_STATUS,
  // add new cmds here

  NODE_CMDS_CNT
};

const char *node_cmds_string[] =
{   
  "OFF\0",
  "ON\0",
  "SAVE ID\0",
  "KEEP ALIVE\0",
  "STATUS\0",
};
STATIC_ASSERT( sizeof( node_cmds_string ) / sizeof( char* ) == NODE_CMDS_CNT, make_arrays_same_size );

typedef struct __node_packet {
  byte id;
  node_cmds cmd;
  byte data;
} node_packet;
//////////////////////////////////////////////////////////////////////////

/*------------------------------------------------------------
Ethernet Shield can sustain 4 (MAX_SOCK_NUM) open sockets at any
given time. 1 should be reserved for webServer, 1 for the UDP
broadasts. Close the UDP when 2 devices are connected in order
to allow the webpage to use another socket. Reopen when a socket
is released by the nodes.
------------------------------------------------------------*/
#define MAX_SERVER_CONNECTIONS 2

/*------------------------------------------------------------------------
VARIABLES
------------------------------------------------------------------------*/

/*------------------------------------------------------------
WebDuino
------------------------------------------------------------*/
File webFile; 

/* This creates an instance of the webserver.  By specifying a prefix
 * of "", all pages will be at the root of the server. */
#define PREFIX ""
WebServer webserver(PREFIX, 80);

// Enter a MAC address for your controller below.
// Newer Ethernet shields have a MAC address printed on a sticker on the shield
byte mac[] = { 0x00, 0xAA, 0xBB, 0xCC, 0xDE, 0x01 };

IPAddress web_ip(192,168,2,210);

// size of buffer used to capture HTTP requests
#define REQ_BUF_SZ   50

// buffered HTTP request stored as null terminated string
char HTTP_req[REQ_BUF_SZ] = {0};
// index into HTTP_req buffer
char req_index = 0;

/*------------------------------------------------------------
PLC
------------------------------------------------------------*/
// default to 11700
EthernetServer server(11700);

// An EthernetUDP instance to let us send and receive packets over UDP
EthernetUDP UDP;
byte IP_addr[4];
unsigned int localPort = 8888;      // local port to listen on
IPAddress udp_ip(255, 255, 255, 255);

EthernetClient old_client[MAX_SERVER_CONNECTIONS];

/*------------------------------------------------------------
Node processing
------------------------------------------------------------*/
boolean node_status[MAX_SERVER_CONNECTIONS];
unsigned long loop_time[MAX_SERVER_CONNECTIONS];
boolean node_connected[MAX_SERVER_CONNECTIONS];
int connected_node_cnt;

/*------------------------------------------------------------------------
FUNCTION PROTOTYPES
------------------------------------------------------------------------*/
boolean client_equal( EthernetClient &clienta, EthernetClient &clientb );
void print_local_ip_address();
void process_cmd_packet( const node_packet &pkt );
void save_local_ip_address();
int send_cmd_to_client( const int &id, const node_cmds &cmd, const byte &data, EthernetClient* client );
void web_response(WebServer &server, WebServer::ConnectionType type, char *url_tail, bool tail_complete);
void update_status(WebServer &server, WebServer::ConnectionType type, char *url_tail, bool tail_complete);
int freeRam();

/*------------------------------------------------------------------------
SETUP
------------------------------------------------------------------------*/
void setup() {
  Serial.begin(9600);

  Serial.println(F("Server Starting"));

  // disable Ethernet chip
  pinMode(10, OUTPUT);
  digitalWrite(10, HIGH);

  // initialize SD card
  Serial.println(F("Initializing SD card..."));
  if(!SD.begin(4)) {
    Serial.println(F("ERROR - SD card initialization failed!"));
    return;    // init failed
  } else {
    Serial.println(F("SD card initialized"));
  }

  // DHCP
  if(Ethernet.begin(mac) == 0) {
    Serial.println(F("Failed to configure Ethernet using DHCP"));
    // initialize the ethernet device not using DHCP:
    Ethernet.begin(mac, web_ip);
  } else {
    Serial.println(F("Eth configured with DHCP"));
  }

  // Start listening on UDP port
  UDP.begin(localPort);

  // start listening for clients
  server.begin();

  /* setup our default command that will be run when the user accesses
   * the root page on the server */
  webserver.setDefaultCommand(&web_response);

  webserver.addCommand("Status", &update_status);

  /* start the webserver */
  webserver.begin();

  // print and save local IP address
  print_local_ip_address();
  save_local_ip_address();

  // node processing
  for( int i = 0; i < MAX_SERVER_CONNECTIONS; i++ ) {
    loop_time[i] = 0;
    node_connected[i] = false;
  }
  connected_node_cnt = 0;

  Serial.println(F("Setup finished"));
}

/*------------------------------------------------------------------------
LOOP
------------------------------------------------------------------------*/
void loop() {

  ////////////////////////
  // Web Server
  /////////////////////////

  char buff[64];
  int len = 64;

  /* process incoming connections one at a time forever */
  webserver.processConnection(buff, &len);

  ////////////////////////
  // Powerline Network
  ////////////////////////

  // broadcast IP address if room for more nodes
  if( connected_node_cnt < MAX_SERVER_CONNECTIONS ) {
    // Broadcast IP address
    UDP.begin(localPort);
    UDP.beginPacket( udp_ip, localPort );
    UDP.write( IP_addr, 4 );
    UDP.endPacket();
  } else {
    //Serial.println( F("Closing UDP resources...") );
    UDP.stop();
  }

  // wait for a new client:
  EthernetClient client = server.available();

  if( client ) {
    boolean alreadyConnected = false;
    int id = 0xFF;

    // determine where to add client in old_client[]
    for( int i = 0; i < MAX_SERVER_CONNECTIONS; i++ ) {
      if( node_connected[i] && old_client[i] && client_equal( client, old_client[i] ) ) {
        alreadyConnected = true;
        id = i;
        break;
      } else if( !node_connected[i] && id == 0xFF ) {
        id = i;
      }
    }

    if (!alreadyConnected) {
      Serial.print( F("SERVER: id = ") );
      Serial.println( id );

      // clead out the input buffer:
      client.flush();
      Serial.println("We have a new client");
      alreadyConnected = true;
      node_connected[id] = true;
      connected_node_cnt++;

      // update client with ID
      send_cmd_to_client( id, NODE_SAVE_ID, id, &client );

      // save into client array
      old_client[id] = client;
      loop_time[id] = 0;
    }
  }

  for( int i = 0; i < MAX_SERVER_CONNECTIONS; i++ ) {
    if( old_client[i] ) {

      boolean data_read = false;
      node_packet packet;

      if( old_client[i].available() >= sizeof( node_packet ) ) {
        data_read = true;

        old_client[i].read( (byte*)&packet, sizeof( node_packet ) );
      }

      if( data_read ) {
        if( packet.cmd != NODE_KEEP_ALIVE || 1) {
          Serial.print(F("RECEIVED --- "));
          Serial.print(F("ID: ")); Serial.print( packet.id );
          Serial.print(F(" CMD: ")); Serial.print( node_cmds_string[ packet.cmd ] );
          Serial.print(F(" Data: ")); Serial.print( packet.data, HEX );
          Serial.println();
        }

        process_cmd_packet( packet );
      }

      // haven't seen a response from client in timeout
      if( ( loop_time[i] != 0 ) && ( millis() - loop_time[i] > 2 * PACKET_WAIT_TIMEOUT ) ) {
        // disconnect node
        Serial.print( i );
        Serial.println(F(" disconnecting node..."));
        old_client[i].flush();
        old_client[i].stop();

        node_connected[i] = false;
        connected_node_cnt--;
      }
    } else {
      // do nothing, no client in slot
    }
  }

}

/*------------------------------------------------------------------------
FUNCTION DEFINITIONS
------------------------------------------------------------------------*/
boolean client_equal( EthernetClient &clienta, EthernetClient &clientb )
{ 
  byte testa[] = { 0, 0, 0, 0 };
  byte testb[] = { 0, 0, 0, 0 };

  clienta.getRemoteIP(testa);
  clientb.getRemoteIP(testb);

  for( int i = 0; i < sizeof( testa ); i++ ) {
    if( testa[i] != testb[i] ) {
      return false;
    }
  }

  return true;
}

void print_local_ip_address()
{
  Serial.print(F("My IP address: "));
  for (byte thisByte = 0; thisByte < 4; thisByte++) {
    // print the value of each byte of the IP address:
    Serial.print(Ethernet.localIP()[thisByte], DEC);
    Serial.print(F("."));
  }
  Serial.println();
}

void process_cmd_packet( const node_packet &pkt )
{
  loop_time[pkt.id] = millis();

  switch( pkt.cmd ) {
    case NODE_OFF:
      break;
    case NODE_ON:
      break;
    case NODE_SAVE_ID:
      break;
    case NODE_KEEP_ALIVE:
      send_cmd_to_client( pkt.id, NODE_KEEP_ALIVE, 0x00, &(old_client[pkt.id]) );
      Serial.print( F("NODE_STATUS: ") );
      Serial.println( pkt.data );
      if( pkt.data == HIGH ) {
        node_status[pkt.id] = true;
      } else {
        node_status[pkt.id] = false;
      }
      break;
    case NODE_STATUS:
      Serial.print( F("NODE_STATUS: ") );
      Serial.println( pkt.data );
      if( pkt.data == HIGH ) {
        node_status[pkt.id] = true;
      } else {
        node_status[pkt.id] = false;
      }
      break;
    default:
      Serial.println(F("CMD NOT KNOWN"));
      break;
  }
}

void save_local_ip_address()
{
  for (byte thisByte = 0; thisByte < 4; thisByte++) {
    IP_addr[thisByte] = Ethernet.localIP()[thisByte];
  }
}

int send_cmd_to_client( const int &id, const node_cmds &cmd, const byte &data, EthernetClient* client )
{
  node_packet packet;
  packet.id = id;
  packet.cmd = cmd;
  packet.data = data;

  if( !(*client) ) {
    Serial.println( F("send_cmd_to_client to NULL") );
    return 0;
  }

  if( cmd != NODE_KEEP_ALIVE || 1 ) {
    Serial.print(F("SENDING --- "));
    Serial.print(F("ID: ")); Serial.print( packet.id );
    Serial.print(F(" CMD: ")); Serial.print( node_cmds_string[ packet.cmd ] );
    Serial.print(F(" Data: ")); Serial.print( packet.data, HEX );
    Serial.println();
  }

  return (*client).write( (byte*)&packet, sizeof( node_packet ) );
}

/* commands are functions that get called by the webserver framework
 * they can read any posted data from client, and they output to the
 * server to send data back to the web browser. */
void web_response(WebServer &server, WebServer::ConnectionType type, char *url_tail, bool tail_complete)
{
  Serial.println(F("Processing web response..."));

  // ////////////////////////////////////
  // Handling POST requests from website
  ///////////////////////////////////////
  if ( type == WebServer::POST)
  {
    Serial.println("Post received");
    bool repeat;
    int id;
    char name[16], value[16];

    /* readPOSTparam returns false when there are no more parameters
     * to read from the input.  We pass in buffers for it to store
     * the name and value strings along with the length of those
     * buffers. */
    repeat = server.readPOSTparam(name, 16, value, 16);

    id = atoi( name ); id--;
    if( node_status[id] ) {
      Serial.print("Sending off to ");
      Serial.println(id);
      send_cmd_to_client( id, NODE_OFF, 0x00, &(old_client[id]) );
      node_status[id] = false;
    } else {
      Serial.print("Sending on to ");
      Serial.println(id);
      send_cmd_to_client( id, NODE_ON, 0x00, &(old_client[id]) );
      node_status[id] = true;
    }

    return;
  }

  // ////////////////////////////////////
  // Handling GET for website page sending
  ///////////////////////////////////////
   /* for a GET or HEAD, send the standard "it's all OK headers" */
  server.httpSuccess();

  if (type == WebServer::GET)
  {
    Serial.println(url_tail);
    URLPARAM_RESULT rc;
    char name[32];
    char value[32];

    // Write HTML file out to client
    webFile = SD.open("index.htm");        // open web page file
    if (webFile) {
        while(webFile.available()) {
            server.write(webFile.read()); // send web page to client
        }
        webFile.close();
    }
  }
}

// Handles sending out LED status updates
void update_status(WebServer &server, WebServer::ConnectionType type, char *url_tail, bool tail_complete)
{
  // Grabbing status from node's keep_alive msg to avoid traffic
  //send_cmd_to_client( 0x01, NODE_STATUS, 0x00, &(old_client[0x01]) );
  Serial.println(F("Updating status to HTTP connection..."));

  server.print("<?xml version = \"1.0\" ?>");
  server.print("<inputs>");
  // light count
  server.print("<count>");
  server.print(connected_node_cnt);
  server.print("</count>");

  for( int i = 0; i < MAX_SERVER_CONNECTIONS; i++ ) {
    if( node_connected[i] ) {
      server.print("<light"); server.print(i + 1); server.print(">");
      if( node_status[i] ) {
          server.print("ON");
      }
      else {
          server.print("OFF");
      }
      server.print("</light"); server.print(i + 1); server.print(">");
    }
  }

  server.print("</inputs>");
}

int freeRam() {
  extern int __heap_start, *__brkval; 
  int v; 
  return (int) &v - (__brkval == 0 ? (int) &__heap_start : (int) __brkval); 
}

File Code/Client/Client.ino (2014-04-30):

/*
  Arduino Client Node
 
 Client program to run Arduino + Ethernet shield plugged into PLN device
 via Ethernet cable communicating to a PLN device also connected to the
 router then to the basestation on the other side.
 
 Circuit:
 * Ethernet shield attached to pins 10, 11, 12, 13
 
 */

#include <SPI.h>
#include <Ethernet.h>




/*------------------------------------------------------------------------
CONSTANTS/TYPES
------------------------------------------------------------------------*/
//////////////////////////////////////////////////////////////////////////
// KEEP TWO SKETCHES IN SYNC BECAUSE ARDUINO'S IDE IS DUMB ///////////////
//////////////////////////////////////////////////////////////////////////
#define STATIC_ASSERT(COND,MSG) typedef char static_assertion_##MSG[(COND)?1:-1]

#define PACKET_WAIT_TIMEOUT 1000

typedef byte node_cmds; enum {
  NODE_OFF = 0,
  NODE_ON,
  NODE_SAVE_ID,
  NODE_KEEP_ALIVE,
  NODE_STATUS,
  // add new cmds here

  NODE_CMDS_CNT
};

const char *node_cmds_string[] =
{   
  "OFF\0",
  "ON\0",
  "SAVE ID\0",
  "KEEP ALIVE\0",
  "STATUS\0",
};
STATIC_ASSERT( sizeof( node_cmds_string ) / sizeof( char* ) == NODE_CMDS_CNT, make_arrays_same_size );

typedef struct __node_packet {
  byte id;
  node_cmds cmd;
  byte data;
} node_packet;
//////////////////////////////////////////////////////////////////////////

#define NODE_RELAY_PIN   2

/*------------------------------------------------------------------------
VARIABLES
------------------------------------------------------------------------*/
// Enter a MAC address for your controller below.
// Newer Ethernet shields have a MAC address printed on a sticker on the shield
byte mac[] = { 0x00, 0xAA, 0xBB, 0xCC, 0xDE, 0x25 };

// Initialize the Ethernet client library
// with the IP address and port of the server
// that you want to connect to (port 80 is default for HTTP):
EthernetClient client;

// An EthernetUDP instance to let us send and receive packets over UDP
EthernetUDP UDP;
unsigned int localPort = 8888;      // local port to listen on

// UDP IP broadcast
char packetBuffer[UDP_TX_PACKET_MAX_SIZE]; //buffer to hold incoming packet,
boolean IP_found = false;

// storage for node's ID grabbed from server
int node_id;

// loop count to determine when to send NODE_KEEP_ALIVE
unsigned long loop_time;
boolean keep_alive_rec;
boolean keep_alive_sent;

/*------------------------------------------------------------------------
FUNCTION PROTOTYPES
------------------------------------------------------------------------*/
void print_local_ip_address();
void process_cmd_packet( const node_packet &pkt );
int send_cmd_to_server( const node_cmds &cmd, const byte &data, EthernetClient* client );

/*------------------------------------------------------------------------
SETUP
------------------------------------------------------------------------*/
void setup() {
  // Open serial communications and wait for port to open:
  Serial.begin(9600);

  // setup pins
  pinMode(NODE_RELAY_PIN, OUTPUT);

  // start the Ethernet connection:
  while(Ethernet.begin(mac) == 0) {
    Serial.println("Failed to configure Ethernet using DHCP");
    // Wait a bit and try again
    delay(100);
  }

  // Start listening on UDP port
  UDP.begin(localPort);

  // print local IP address
  print_local_ip_address();

  // disconnect init
  keep_alive_rec = false;
  keep_alive_sent = false;
}

/*------------------------------------------------------------------------
LOOP
------------------------------------------------------------------------*/
void loop() {
    // if there's data available, read a packet
  int packetSize = UDP.parsePacket();

  if(packetSize && !IP_found)
  {
    Serial.print("Received packet of size ");
    Serial.println(packetSize);
    Serial.print("From ");
    IPAddress remote = UDP.remoteIP();
    for (int i =0; i < 4; i++)
    {
      Serial.print(remote[i], DEC);
      if (i < 3)
      {
        Serial.print(".");
      }
    }
    Serial.print(", port ");
    Serial.println(UDP.remotePort());

    // read the packet into packetBufffer
    UDP.read(packetBuffer,UDP_TX_PACKET_MAX_SIZE);
    Serial.println("Contents:");
    Serial.println(packetBuffer);

    IP_found = true;

    while( !client.connect( UDP.remoteIP(), 11700) ) {
      Serial.println("Client cannot connect...");
      delay(100);
    }

    while( !client.connected() ) {
      Serial.println("Waiting to connect...");
    }

    // bring up connection with KEEP_ALIVE cmd
    send_cmd_to_server( NODE_KEEP_ALIVE, digitalRead( NODE_RELAY_PIN ), &client );

    Serial.println("CONN BROUGHT UP");
  }

  if( IP_found )
  {
    boolean data_read = false;
    int data_timeout = 0;
    node_packet packet;

    if( client.available() >= sizeof( node_packet ) ) {
      data_read = true;

      client.read( (byte*)&packet, sizeof( node_packet ) );
    }

    if( data_read ) {
      if( packet.cmd != NODE_KEEP_ALIVE || 1 ) {
        Serial.print("RECEIVED --- ");
        Serial.print("ID: "); Serial.print( packet.id );
        Serial.print(" CMD: "); Serial.print( node_cmds_string[ packet.cmd ] );
        Serial.print(" Data: "); Serial.print( packet.data, HEX );
        Serial.println();
      }

      process_cmd_packet( packet );
    }

    if( millis() - loop_time > PACKET_WAIT_TIMEOUT ) {
      // keep alive sent and didn't receive a reply
      // close connection to server, reset checks
      if( keep_alive_sent && !keep_alive_rec ) {
        Serial.println("TIMEOUT disconnection...");
        IP_found = false;
        client.flush();
        client.stop();
        keep_alive_sent = false;
        keep_alive_rec = true;
      } else {
        send_cmd_to_server( NODE_KEEP_ALIVE, digitalRead( NODE_RELAY_PIN ), &client );
      }
    }

  } else {
    Serial.print("IP NOT FOUND");
    Serial.println();
  }
}

/*------------------------------------------------------------------------
FUNCTION DEFINITIONS
------------------------------------------------------------------------*/
void print_local_ip_address()
{
  Serial.print("My IP address: ");
  for (byte thisByte = 0; thisByte < 4; thisByte++) {
    // print the value of each byte of the IP address:
    Serial.print(Ethernet.localIP()[thisByte], DEC);
    Serial.print(".");
  }
  Serial.println();
}
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

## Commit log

2014-01-18 Adding power modem datasheet
2014-01-18 Adding Eagle Library for Power Modem
2014-01-18 Created simple breakout for power modem
    [Power_Modem_Breakout.brd, Power_Modem_Breakout.sch]
2014-01-18 Added silkscreen layer
    [Power_Modem_Breakout.brd]
2014-01-18 Adding OSH Park DRC file
    [Power_Modem_Breakout.brd]
2014-01-18 Added really important things to breakout
    [Power_Modem_Breakout.brd]
2014-01-18 Fixed PL so it renders correctly
    [Power_Modem_Breakout.brd]
2014-01-18 Fixed my name
    [Power_Modem_Breakout.brd]
2014-01-23 Fixed my name layer.
    [Power_Modem_Breakout.brd]
2014-01-29 Adding schematic for power line breakout
    [Data_Over_Power_Breakout.brd, Data_Over_Power_Breakout.sch]
2014-01-29 Added DOP Board
    [Data_Over_Power_Breakout.brd, Data_Over_Power_Breakout.sch]
2014-02-24 Add test code to use one Uno + 2 PLN boards
2014-03-02 Add webserver code and webpage
    This code will communicate with the webpage via an XML response.
    The status reflected is of the pin 7 and 8 button being emulated
    by a wire connected to GND (off) or 3.3V (on). The code contains
    the first pass at adding elements on the fly commented out.
2014-03-18 Update one Uno code to signal LED
2014-03-24 Adding schematic for long term hardware design
    [Base_Station.sch]
2014-03-25 Added Schematic for low cost coupling board
    Hopefully I didn't mess it up too badly
    [Base_Station.sch]
2014-03-26 Finished schematic for low cost coupling board.
    [Base_Station.sch]
2014-03-27 Partially completed low cost coupling board
    Decided it wasn't necessary tonight
    [Base_Station.brd, Base_Station.sch]
2014-04-10 Add initial code for basestation and node
    The Code folder now contains the code for both Arduinos doing
    communication through the powerline. The layout of the components
    is detailed in the header of the files. This should enable
    dynamic connection to the server via grabbing a UDP broadcast
    of the basestation's IP address. The basestation will see the
    client and send commands through the PLN device. The node device
    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
2014-04-10 Reset connection to server on disconnect
    If TCP connection to server has gone down, look for UDP broadcast
    and reconnect to new server IP.
    Issue: #10
    [Client.ino]
2014-04-10 Fix send_cmd_to_client function
    Update function to send data to the individual client passed into
    the function instead of to all connected clients.
    [Server.ino]
2014-04-10 Update receiving algorithm on client side
    We can assume the data will be received correctly because of using
    the TCP connection to exchange the data.
    [Client.ino, Server.ino]
2014-04-10 Add dynamic node addition/removal
    client.connected() never seems to disconnect on the server side.
    Use both client.connected() and whether the server can write to
    the client to determine the status of the TCP connection. Server
    will determine that client has been dropped and begin searching
    for a new clients again.
    Issue: #2
    [Client.ino, Server.ino]
2014-04-12 Add on/off response to commands
    Initialize relay pin (5) as output and set the value upon receipt of
    the NODE_OFF or NODE_ON commands.
    Issue: #4
    [Client.ino]
2014-04-16 Add status command and server command parsing
    Node can now return status to server. Server can now parse commands
    /respones sent back from node devices.
    Issue: #13
    [Client.ino, Server.ino]
2014-04-16 Add node on/off functionality with status update
    Issue: #6
    [Client.ino, Server.ino]
2014-04-18 Send NODE_STATUS to server after NODE_ON/OFF
    Process NODE_ON/OFF and send NODE_STATUS to server to update its
    state for the selected node.
    Issue: #16
    [Client.ino]
2014-04-18 Add node disconnecting from base logic
    The nodes can now detect that the base has been disconnected and
    they will starting searching for new base. They rely on a cmd
    sent to server (NODE_KEEP_ALIVE) receiving a reply back under the
    time limit (2000 loops). Every NODE_KEEP_ALIVE sent from server
    contains the status of the relay pin, so use this to update the
    node_status on the server side. This will cause less traffic than
    an explicit NODE_STATUS command although that functionality is
    still there.
    Issue: #15
    [Client.ino, Server.ino]
2014-04-18 Add server disconnecting from node logic
    Server will disconnect from node if it hasn't seen a NODE_KEEP_ALIVE
    in (2 * LOOP_COUNT_RESET). It will then return to the accepting
    connections state. The current timeout is loop cycle based but
    it would be better to do it time based.
    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
    [Client.ino, Server.ino]
2014-04-18 Start multinode support
    Setup arrays for node status/timeout and for individual Ethernet
    Client storage per connected node. Limit connections by max sockets
    available to Ethernet Shield. Most accesses are hard coded due to
    the server only giving out the 0x01 ID to all connected nodes.
    Looping over the arrays needs to be added to finish this setup.
    Issue: #7
    [Client.ino, Server.ino]
2014-04-21 #14 Webpage now dynamically generates buttons for lights. Light state is also represented by button color. Commanding is broken for now
2014-04-21 #14 Device buttons now generate unique post messages
2014-04-22 Change node/server timeout to time based
    Nodes now disconnect from server if a KEEP_ALIVE isn't received
    within 0.5 seconds from sending one. Server now disconnects if a
    KEEP_ALIVE isn't recieved from a node within 1 second.
    Add looping over multiple nodes. This needs to be tested before it
    can be verified.
    Issue: #18
    Issue: #5
    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
    [Client.ino, Server.ino]
2014-04-22 Complete multi-node processing
    Multiple nodes can now connect. Nodes will timeout individually
    based on the previous timeout values. A new ID will be given to a
    new connection that hasn't been established before. All Serial.
    print/println strings have now been moved to PROGMEM to save RAM.
    IMPORTANT:
    To get this patch to work, you must copy the files in
    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
2014-04-30 Close UDP socket when MAX conns reached
    Close UDP socket to open up more sockets for other nodes and/or
    webserver traffic.
2014-04-30 Update MAC and pin for demo presentation
2014-04-30 Add physical housing files
    Add physical housing files created in Autodesk Inventor. Contains
    the individual drawing files as well as an assembly file with the
    two parts placed together. The .stl files were generated to send
    to the 3D printer and are included.
    [SD_BaseStation_Box.ipt, SD_BaseStation_Box.stl, SD_BaseStation_Enclosure.iam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]
2014-04-30 Change units of .stl files to inches
    [SD_BaseStation_Box.ipt, SD_BaseStation_Box.stl, SD_BaseStation_Lid.stl]
2014-05-04 Buttons are now bigger
2014-05-04 Schematic for nodes
    Includes dpl circuit, relay, and arduino itself
    [Shield_Eth06-REV3.brd, Shield_Eth06-REV3.sch, arduino_Uno_Rev3-02-TH.brd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]
2014-05-04 oops, don't add dummy buttons
2014-05-04 update title of device control center
2014-05-05 Started node pcb layout
    not finished yet
    [node_with_dpl_and_relay.brd, node_with_dpl_and_relay.sch]
2014-05-13 node pcb done
    should work
    [node_with_dpl_and_relay.brd, node_with_dpl_and_relay.sch]

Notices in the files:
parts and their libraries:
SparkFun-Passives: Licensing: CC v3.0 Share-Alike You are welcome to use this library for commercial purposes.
